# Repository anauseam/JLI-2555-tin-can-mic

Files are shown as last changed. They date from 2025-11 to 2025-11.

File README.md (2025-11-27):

# JLI-2555-tin-can-mic

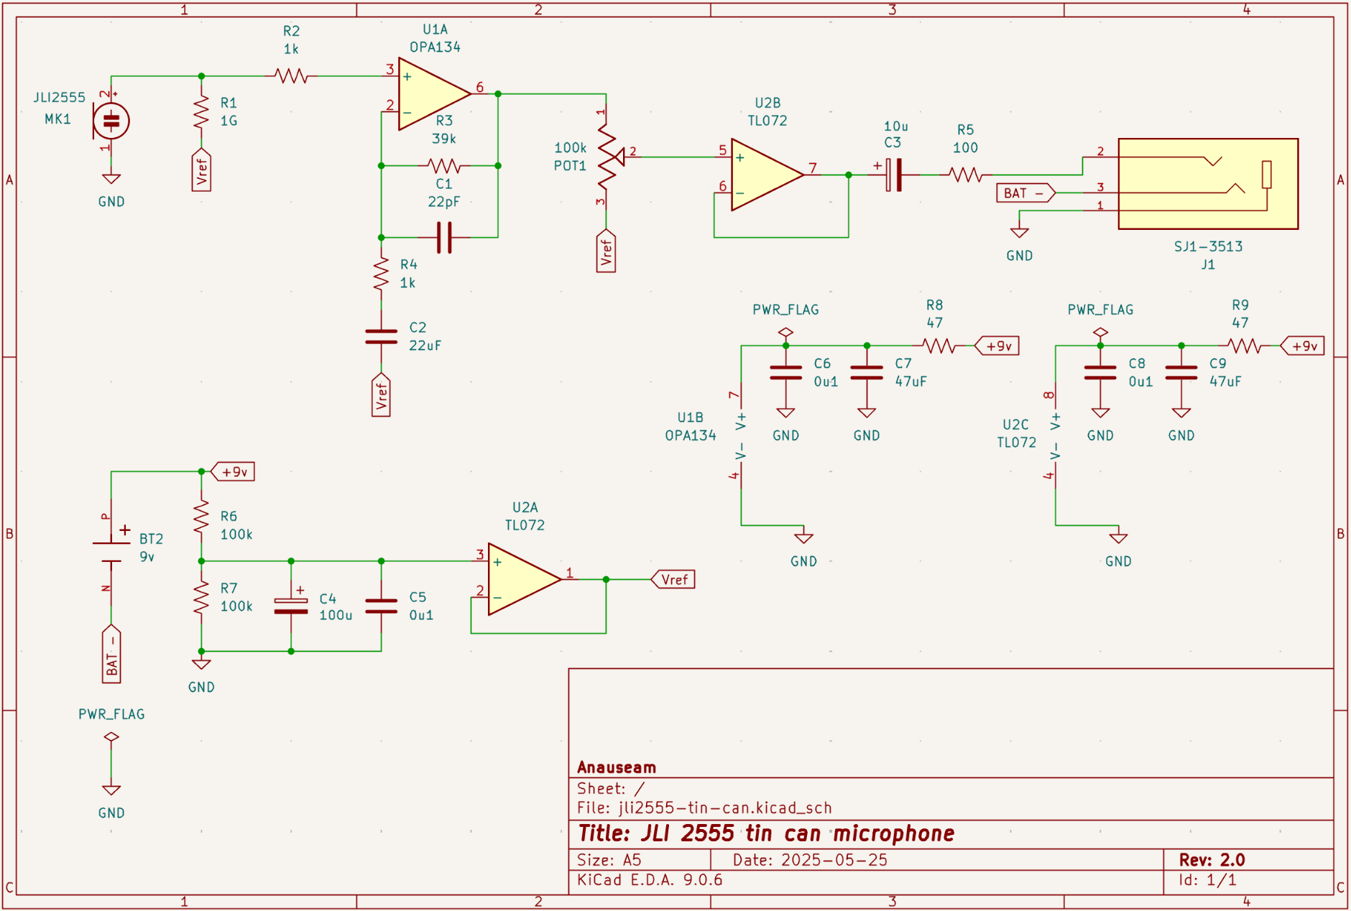
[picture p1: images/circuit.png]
tin can circuit


A unprofessional "Mid"-Fi mic using a JLI 2555, meant to be housed in a tin can.

## Specs

Output voltage is designed to output a commercial level line signal via a TS connection.

All the components were designed to be purely through hole and non-obsolete, thus limiting the choices drastically.

If you would like a circuit that you can order pre made refer to the [WIP] Repo.

## Notes / Known issues

Because the potentiometer is DC biased, when the potentiometer collects dust years down the road there will be a scratching nose when turning the knob. Given that this is a literal mic housed in a tin can, I can accept this fact

Yes the entire circuit is running off of a 9v. This makes things as simple as possible, perfect for a proof of concept tin can microphone. Reasons for the unipolar supply:

- Adding a bipolar supply (two batteries) would introduce a new array of issues (e.g. uneven battery drain, size)

The biggest issue (IMO) is the OPA134 itself. Although it does have an excellent noise floor compared to standard op amps, compared a something like the OPA1642, or a proper discrete JFET, it has a noise floor of about 12.45 nV/sqrt(Hz) when considering the op amp's voltage noise and the voltage noise from the affect of the op amp's current noise and 1G resistor.

## TODO

Current the PCB is haphazardly connected, a proper layout will be completed once testing of the original circuit is done.

I will probably create a proper pcb with SMT

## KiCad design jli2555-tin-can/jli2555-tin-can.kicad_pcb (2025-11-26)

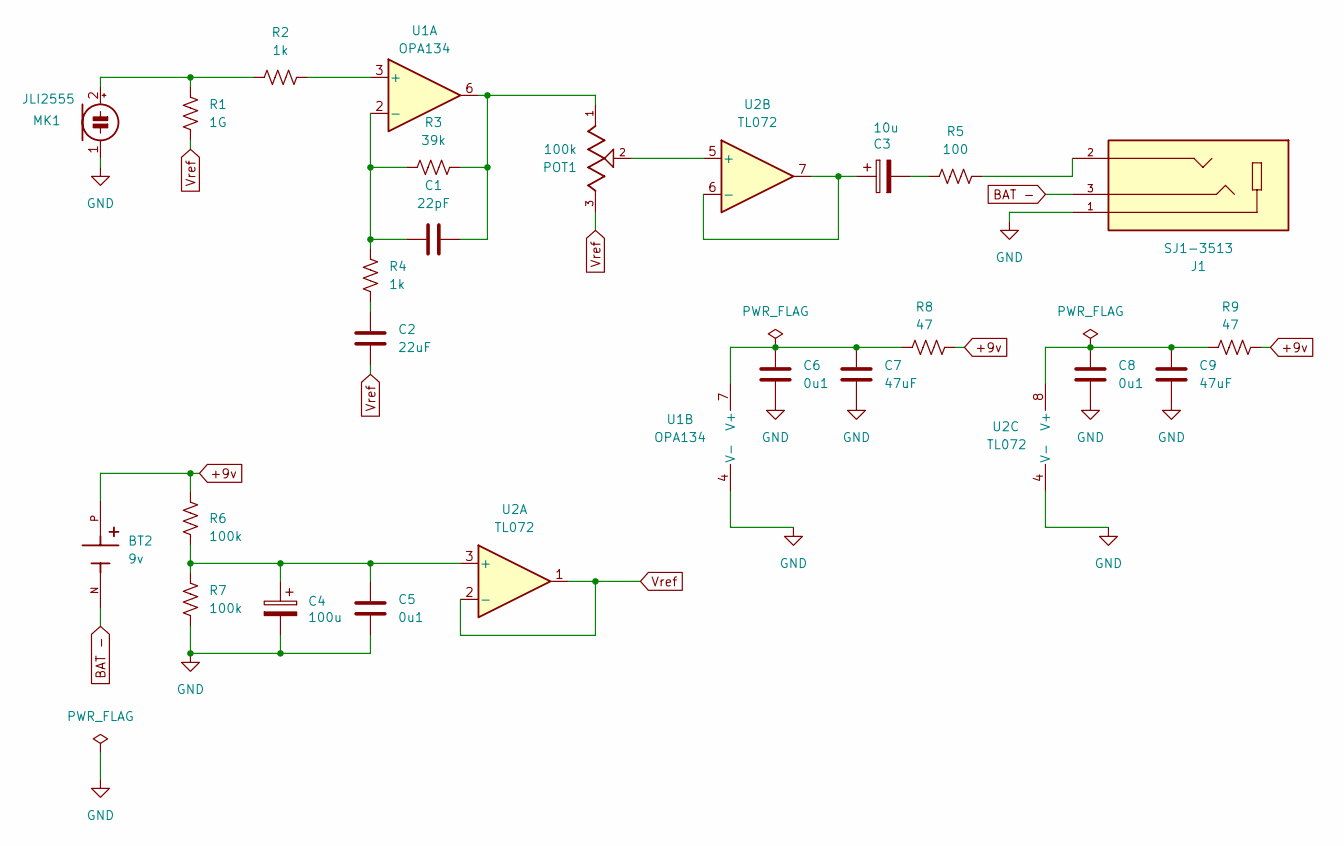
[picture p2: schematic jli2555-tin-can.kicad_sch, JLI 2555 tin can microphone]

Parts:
BT2: 9v; BAT_1294; PARTREV C
C1: 22pF; C_Disc_D5.0mm_W2.5mm_P2.50mm
C2: 22uF; C_Disc_D5.0mm_W2.5mm_P2.50mm
C3: 10u; CP_Radial_D5.0mm_P2.50mm
C4: 100u; CP_Radial_D6.3mm_P2.50mm
C5, C6, C8: 0u1; C_Disc_D5.0mm_W2.5mm_P2.50mm
C7, C9: 47uF; C_Disc_D5.0mm_W2.5mm_P2.50mm
J1: SJ1-3513; CUI_SJ1-3513; PARTREV 1.03
MK1: JLI2555; SolderWire-0.1sqmm_1x02_P3.6mm_D0.4mm_OD1mm
POT1: 100k; POT_PTN16-A100120K1A1; PARTREV 1.0
R1: 1G; R_Axial_DIN0207_L6.3mm_D2.5mm_P10.16mm_Horizontal
R2, R4: 1k; R_Axial_DIN0207_L6.3mm_D2.5mm_P10.16mm_Horizontal
R3: 39k; R_Axial_DIN0207_L6.3mm_D2.5mm_P10.16mm_Horizontal
R5: 100; R_Axial_DIN0207_L6.3mm_D2.5mm_P10.16mm_Horizontal
R6, R7: 100k; R_Axial_DIN0207_L6.3mm_D2.5mm_P10.16mm_Horizontal
R8, R9: 47; R_Axial_DIN0207_L6.3mm_D2.5mm_P10.16mm_Horizontal
U1: OPA134; DIP-8_W7.62mm_Socket
U2: TL072; DIP-8_W7.62mm_Socket

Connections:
+9v: BT2.P, R6.1, R8.2, R9.2
BAT -: BT2.N, J1.3
GND: C4.2, C5.1, C6.1, C7.1, C8.1, C9.1, J1.1, MK1.1 (-), R7.2, U1.4 (V-), U2.4 (V-)
unnamed: C1.2, POT1.1, R3.2, U1.6
unnamed: C2.2, R4.2
unnamed: C3.2, R5.1
unnamed: J1.2, R5.2
unnamed: MK1.2 (+), R1.1, R2.1
unnamed: R2.2, U1.3 (+)
unnamed: C1.1, R3.1, R4.1, U1.2 (-)
unnamed: C6.2, C7.2, R8.1, U1.7 (V+)
unnamed: C4.1, C5.2, R6.2, R7.1, U2.3 (+)
unnamed: POT1.2, U2.5 (+)
unnamed: C3.1, U2.6 (-), U2.7
unnamed: C8.2, C9.2, R9.1, U2.8 (V+)
Vref: C2.1, POT1.3, R1.2, U2.1, U2.2 (-)

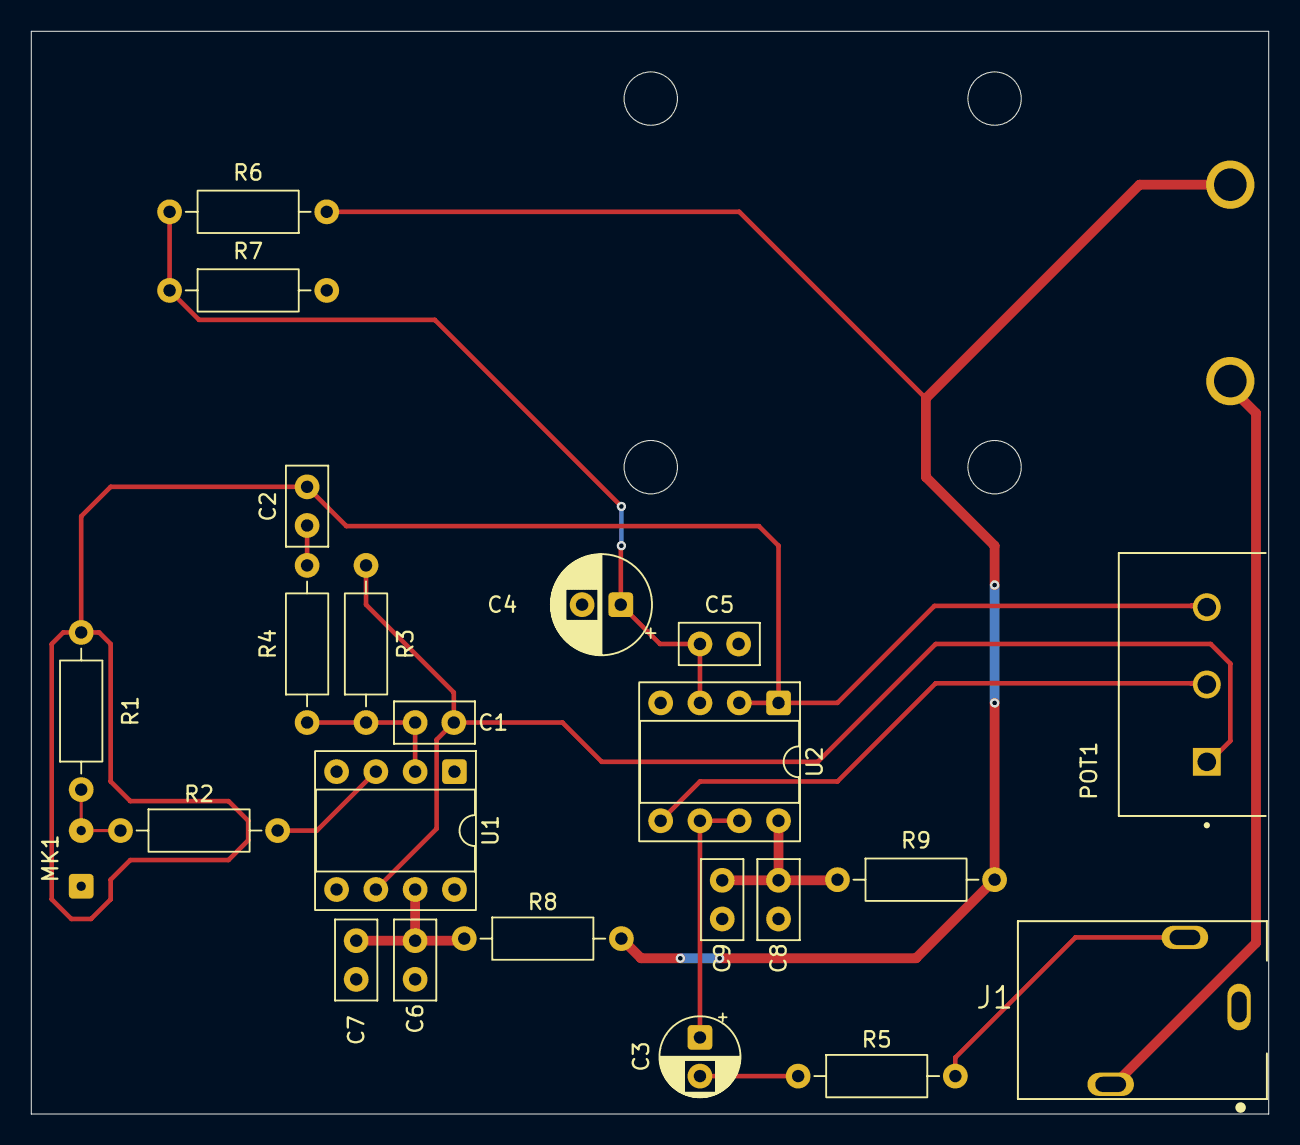
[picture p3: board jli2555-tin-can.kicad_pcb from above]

Board: 2 copper layers, 80.0 x 70.0 mm, 24 parts (1 on the bottom side), 16 nets.

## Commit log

2025-11-25 finalize the -9v powered circuit design. Renamed entire project
    [jli2555-tin-can.kicad_pcb, jli2555-tin-can.kicad_sch, jli2555_preamp_lite.kicad_pcb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]
2025-11-26 Finalization of the first printed prototype, revision 1
    [jli2555-tin-can-B_Cu.gbl, jli2555-tin-can-B_Mask.gbs, jli2555-tin-can-B_Paste.gbp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]
2025-11-27 add circuit image to readme
